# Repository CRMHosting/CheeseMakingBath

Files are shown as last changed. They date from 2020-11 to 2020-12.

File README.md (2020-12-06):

# CheeseMakingBath
### Общее описание
Контроллер для сыродельной ванны. Является дополниительным вспомогательным оборудованием, устанавливаемым помимо автоматики, использующейся в сыроварне.
Не подключается к исполнительным устройствам. Является средством сигнализации о возникновении тех или иных условий и ситуаций. В частности в настоящий момент используется для помещения термо-щупа в ванну с молоком и отображения текущего значения температуры молока, а так же сигнализация о достижении пороговых значений пр инагреве и охлаждении молока. Опционально предусмотрено добавление в схему датчика кислотности. Позволяет выводить показания кислотности молока и сырного зерна на экран, а также сигнализировать о достижении определенной кислотности. Так же имеется функция таймера.

### Состав файлов
- Nextion - Папка с проектом для контактного дисплея Nextion
  - fonts - Папка с сгенеренными шрифтами для дисплея Nextion
  - images - Папка с графическими файлами, формирующими кнопки и всевозможные элементы в дисплее Nextion
    - buttons - Изображения разнообразных кнопок
    - headers - Изображения заголовков некоторых разделов
    - temperature - Разнообразные значки с температурой
    - other - Прочие графические изображения
  - chees.HMI - Проект для редактора Nextion Editor
  - chees.tft - Скомпилированный файл проекта для загрузки в дисплей Nextion
- docs - Папка с вспомогательными файлами проекта
- Schema.fzz - Проект для Fritzing с схемой платы
- cheeseMakingBath.ino - Скетч для управляющей платы для Arduino

### Схема подключения
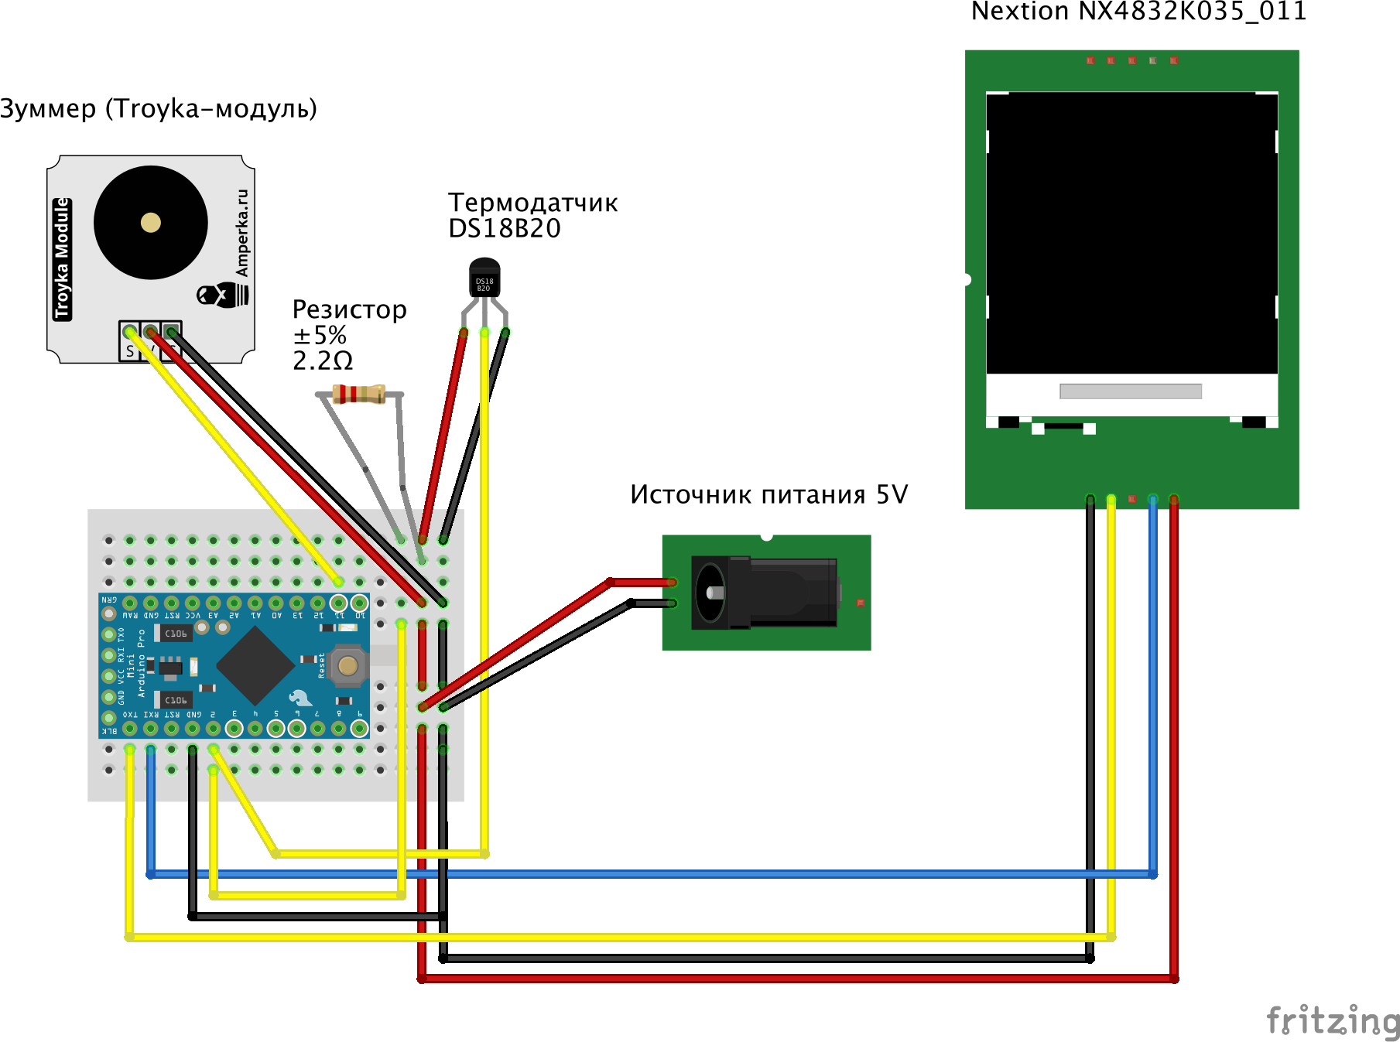
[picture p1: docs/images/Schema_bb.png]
Схема подключения

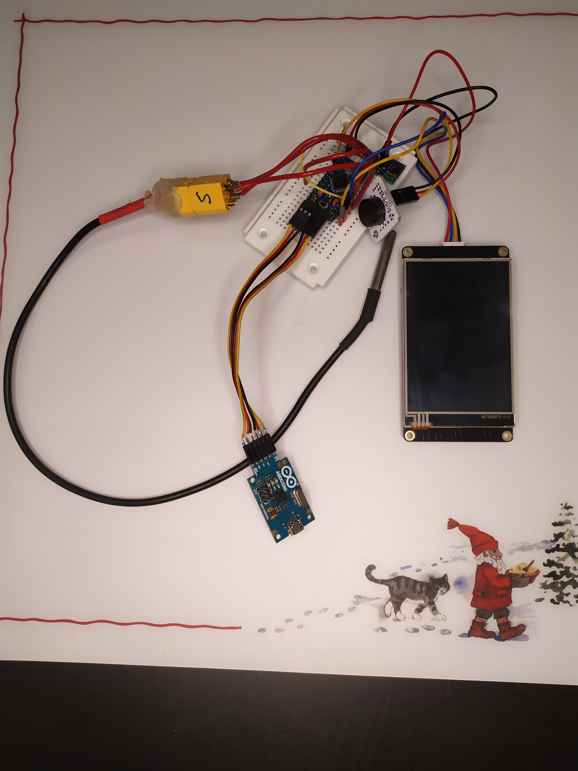
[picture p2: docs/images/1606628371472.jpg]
Демо-стенд

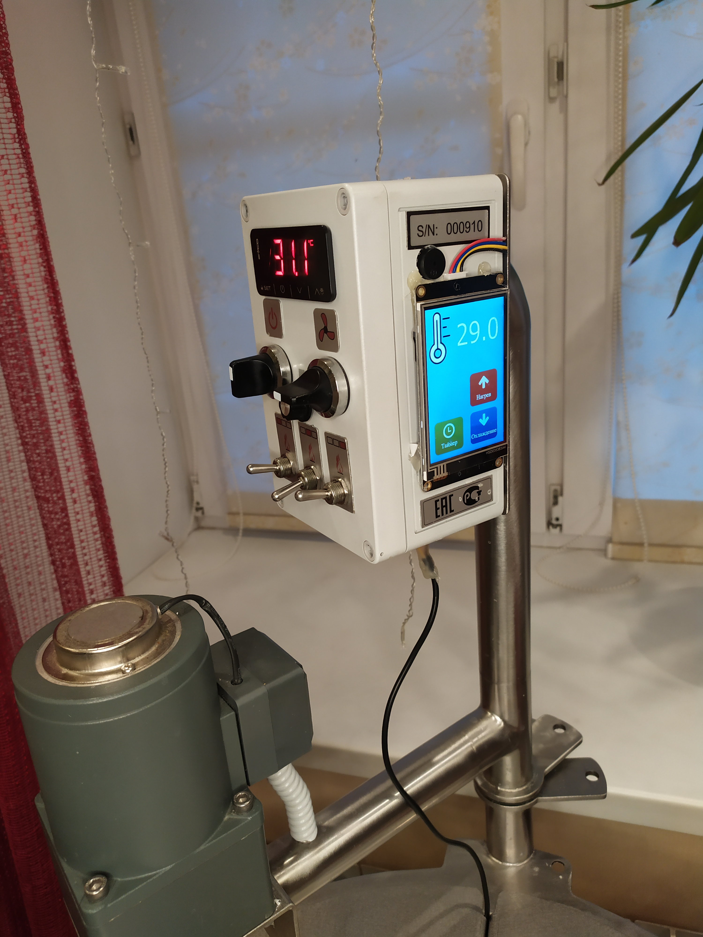
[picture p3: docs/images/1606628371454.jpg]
Как выглядит конечное устройство


### Скрины на экране
- **Главный экран** - Показывает текущую температуру среды, в которую опущен щуп. Есть возможность включить таймер, а также поставить программу нагрева или охлаждения до определенной температуры.
- **Датчик кислотности** - Опционально. Если используется, то позволяет на главном экране видеть текущее значение кислотности молока (или сырного зерна), а так же позволяет установить значение кислотности, при достижении которого микроконтролллер начинает пищщать.
- **Таймер** - Позволяет в пару касаний включить таймер на 30 секунд, 1, 2, 5, 10, 15, 20, 30 минут или 1 час. Когда таймер подойдет к нулю, то экран начинает мигать, а зуммер начинает пищщать. В целом его неплохо слышно из другой комнаты. Но если есть сильные посторонние звуки (музыка громко играет, телевизор и так далее), то можно и не услышать.
- **Нагрев** - Данный режим позволяет подать сигнал, когда термодатчик почувствует температуру, достигшую заданной или превышающую ее. В пару касаний можно установить предустановленную температуру или указать температуру самостоятельно. Выбор температуры вручную начинается от текущей температуры датчика до 99°С
- **Охлаждение** - Режим схож с режимом **Нагрев**, только контроллер ожидает понижение температуры измеряемой среды. Можно указать или предустановленное значение, и тогда при достижении этой температуры будут подаваться звуковые сигналы и дисплей начнет мигать. Можно задать любое значение для температуры, начиная от текущей температуры, диагностируемой датчиком, до 4°С

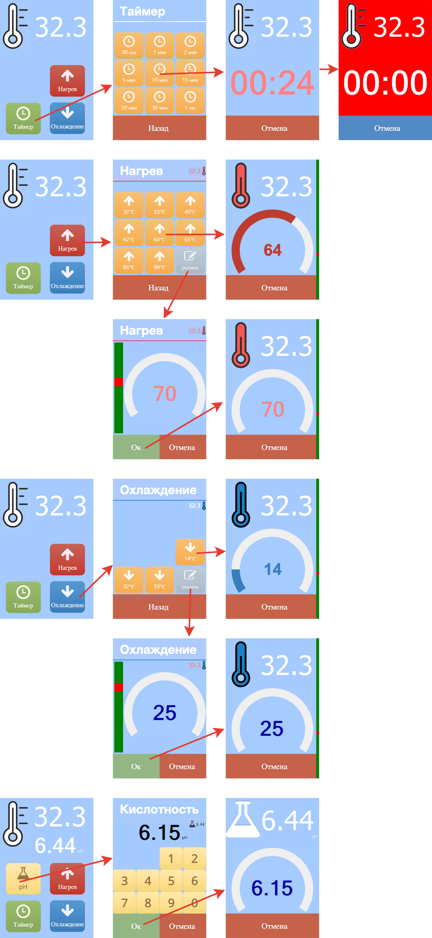
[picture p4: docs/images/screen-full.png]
Схемы экранов в Nextion


### Используемые материалы и устройства
- [Цветной сенсорный дисплей Nextion Enhanced 3,5” / 480×320](https://amperka.ru/product/display-nextion-enhanced-nx4832k035) - 3 190р
- [Зуммер (Troyka-модуль)](https://amperka.ru/product/troyka-buzzer) - 200р
- [Breadboard Mini](https://amperka.ru/product/breadboard-mini-colored) - 190р
- Контроллер: подойдет любой, где есть пины RX и TX, например вот эта: [Iskra Nano Pro](https://amperka.ru/product/iskra-nano-pro) - 390р
- [Герметичный датчик температуры DS18B20](https://amperka.ru/product/sealed-temperature-sensor-ds18b20) - 240р
- [Датчик кислотности жидкости DFRobot](https://amperka.ru/product/ph-sensor) - 3 040р
- Провода и всякие разъемчики

*Цены на ноябрь 2020 года, курс доллара: 75.85р*

Альтернативы на Aliexpress позволят значимо сэкономить!

### Дополнительные ссылки
- [Trello](https://trello.com/b/lrTgKUwX/%D1%81%D1%8B%D1%80%D0%BE%D0%B4%D0%B5%D0%BB%D0%B8%D0%B5) со всем, что удалось найти и узнать по сыроделию
- [Сайт](http://cheesehead.ru/) по сыроделию
- [Форум](http://forumcheesehead.ru/) по сыроделию
- [Книга](https://eksmo.ru/book/sovremennoe-syrodelie-dlya-vsekh-ITD1092554/) по сыроделию
- [Arduino IDE](https://www.arduino.cc/en/software) - Редактор для программирования Arduino и загрузки программ в микроконтроллер
- [Nextion Editor](https://nextion.tech/nextion-editor/) - Редактор для проектирования экранов в сенсорном дисплее Nextion
- [Fritzing](https://fritzing.org/download/) - Программа для создания схем сборки печатных плат и комплектующих
- [DFRobot](https://wiki.dfrobot.com/PH_meter_SKU__SEN0161_) - Страница с описанием и калибровочным скетчем для датчика кислотности

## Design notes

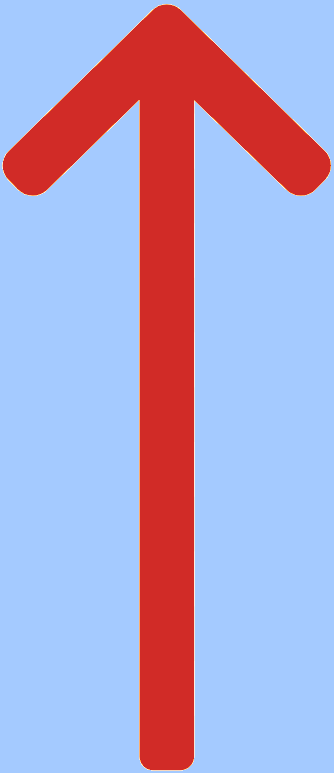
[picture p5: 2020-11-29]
Nextion/images/temperature/arrow-up-red.png

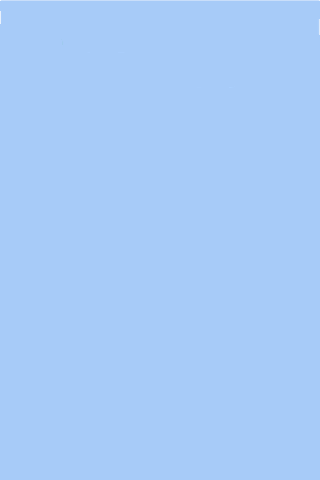
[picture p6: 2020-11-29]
Nextion/images/other/chees_320_480_background.png

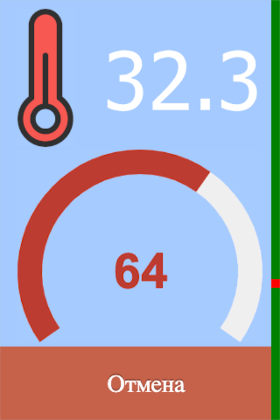
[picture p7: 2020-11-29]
docs/images/h-run-280x420.png

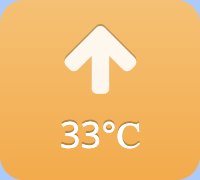
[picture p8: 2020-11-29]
Nextion/images/buttons/heat-buttons-33.png

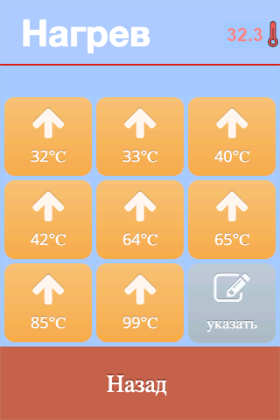
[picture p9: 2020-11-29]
docs/images/h-280x420.png

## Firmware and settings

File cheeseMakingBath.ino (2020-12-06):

// Видеообзоры и уроки работы с ARDUINO на YouTube-канале IOMOIO: https://www.youtube.com/channel/UCmNXABaTjX_iKH28TTJpiqA
// Программа для управления сыроварней - подключение к Датчику температуры и вывод данных в дисплей Nextion

#include <OneWire.h>                  // Подключаем библиотеку для взаимодействия с устройствами, работающими на шине и по протоколу 1-Wire
#include <DallasTemperature.h>        // Подключаем библиотеку с функциями для работы с DS18B20 (запросы, считывание и преобразование возвращаемых данных)

#define ONE_WIRE_BUS 2                // Указываем пин подключения data-вывода датчика температуры
#define term_power 4                  // Указываем пин подключения питания датчика температуры

// Таймер очередного считывания значений с датчика температуры
unsigned long tempReadTimer;

// Частота считывания температуры с датчика (сек)
int tempReadDuration = 4;

// Возможность считывать температуру в текущий момент
boolean tempReadEnable = true;

// Порт для пищалки
#define BEEPER_PIN 11

// Порт для pH-метра
#define pHSensorPin A0

#define pHTimerInterval 20
#define printInterval 800
#define ArrayLenth  40
int pHArray[ArrayLenth];
int pHArrayIndex=0;
#define pHOffset 0.39   // Коэффициент компенсации помех, является разницей между pH эталонного раствора (7.01pH) и тем, что фактически показывает прибор

OneWire oneWire(ONE_WIRE_BUS);        // Сообщаем библиотеке об устройстве, работающем по протоколу 1-Wire
DallasTemperature sensors(&oneWire);  // Связываем функции библиотеки DallasTemperature с нашим 1-Wire устройством (DS18B20)

void setup(void)
{
  Serial.begin(9600); // Порт на Nextion будет 4800, 9600 или 19200, какой то глюк
  Serial.setTimeout(50); // Таймаут ожидания что все пришло
  sensors.begin();                // Запускаем библиотеку измерения температуры
  pinMode(term_power, OUTPUT);    // Определяем пин подключения питания датчика температуры

  // Лампочка на плате
  pinMode(LED_BUILTIN, OUTPUT);

  // Бипер
  pinMode(BEEPER_PIN, OUTPUT);
  
}


float temperature() { // Измеряем температуру 10 секунд
  digitalWrite(term_power, HIGH);                // Включаем питание датчика температуры
  delay(100);                                    // Задержка перед первым измерением 
  sensors.requestTemperatures();                 // Запрос на измерение температуры (1-й ошибочный)
  delay(500);                                    // Задержка перед поторным измерением
  sensors.requestTemperatures();                 // Запрос на измерение температуры (повторный)
  float t = float(sensors.getTempCByIndex(0));   // Получаем значение температуры
  digitalWrite(term_power, LOW);                 // Отключаем питание датчика температуры
//  delay(2000);                                   // Задержка, чтобы датчик не нагревался от частых измерений
  return(t);                                     // Возвращаем значение температуры в место вызова функции
}


void loop() {

  int frequency;

  // Переменные для измерения pH
  static unsigned long pHTime = millis();
  static unsigned long printTime = millis();
  static float pHValue,voltage;

  if(millis() >= tempReadTimer + tempReadDuration * 1000 && tempReadEnable) {
      // Настало время считать данные с датчика и отправить их в Nextion

      //digitalWrite(LED_BUILTIN, HIGH);

      // Отправляем значение температуры в Nextion
      Serial.print("main.tIn.txt=\"");
      Serial.print(String(temperature()*10));
      Serial.print("\"");
      Serial.write(0xFF);
      Serial.write(0xFF);
      Serial.write(0xFF);
      // Отправляем значение кислотности в Nextion
      Serial.print("main.pHIn.txt=\"");
      Serial.print(String(pHValue*100));
      Serial.print("\"");
      Serial.write(0xFF);
      Serial.write(0xFF);
      Serial.write(0xFF);
      //digitalWrite(LED_BUILTIN, LOW);

      // Обновляем таймер
      tempReadTimer = millis();

  }

  if(millis()-pHTime > pHTimerInterval)
  {
    pHArray[pHArrayIndex++]=analogRead(pHSensorPin);
    if(pHArrayIndex==ArrayLenth)pHArrayIndex=0;
    voltage = avergearray(pHArray, ArrayLenth)*5.0/1024;
    pHValue = 3.5*voltage+pHOffset;
    pHTime=millis();
    
  }
  
  // Получаем управляющие сигналы
  if (Serial.available() > 0) {
      // Что то пришло на вход

      // Считываем данные из порта
      String code = Serial.readString();
      
      // Определяем управляющие коды
      if(code == "beepOn") {
          // Пришла команда биперу - гудеть
          digitalWrite(LED_BUILTIN, HIGH);
          //tone(BEEPER_PIN, 800,500);
          tone(BEEPER_PIN, 1000,500);
          // Запрещаем мерить температуру, пока гудит биппер
          tempReadEnable = false;
      } else if(code == "beepOff") {
          // Пришла команда биперу - выключиться
          digitalWrite(LED_BUILTIN, LOW);
          noTone(BEEPER_PIN);
          
          // Включаем возможность мерить температуру
          tempReadEnable = true;
      }
  
  }

}

double avergearray(int* arr, int number){
  int i;
  int max,min;
  double avg;
  long amount=0;
  if(number<=0){
    Serial.println("Error number for the array to avraging!/n");
    return 0;
  }
  if(number<5){   //less than 5, calculated directly statistics
    for(i=0;i<number;i++){
      amount+=arr[i];
    }
    avg = amount/number;
    return avg;
  }else{
    if(arr[0]<arr[1]){
      min = arr[0];max=arr[1];
    }
    else{
      min=arr[1];max=arr[0];
    }
    for(i=2;i<number;i++){
      if(arr[i]<min){
        amount+=min;        //arr<min
        min=arr[i];
      }else {
        if(arr[i]>max){
          amount+=max;    //arr>max
          max=arr[i];
        }else{
          amount+=arr[i]; //min<=arr<=max
        }
      }//if
    }//for
    avg = (double)amount/(number-2);
  }//if
  return avg;
}

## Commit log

2020-11-29 Стартовый импорт
2020-11-29 Фото прототипа и реализации
2020-11-29 Скрины с дисплея + схема в Fritzing
    [Schema.fzz]
2020-11-29 Схема подключения
2020-11-29 Скрины экрана в более мелком разрешении
2020-11-30 Картинки с описаниями
2020-11-30 Убрал лишние файлы
2020-11-30 добавили .gitignore
2020-12-06 Добавлена поддержка датчика кислотности
2020-12-06 Update README.md
    Добавлено описание модуля с датчиком кислотности
